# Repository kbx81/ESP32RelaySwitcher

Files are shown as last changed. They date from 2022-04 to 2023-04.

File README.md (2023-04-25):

# kbx's 8-channel ESP32-Powered Relay + I/O Board

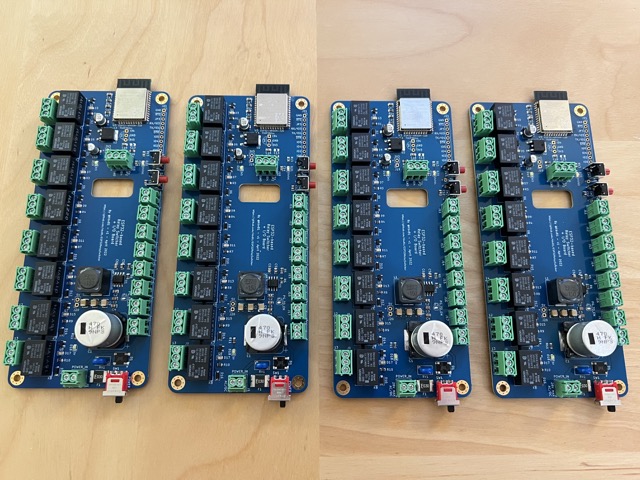
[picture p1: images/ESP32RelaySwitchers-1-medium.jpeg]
kbxESP32RelaySwitcher


## What?

A simple ESP32-based board with eight relays for switching various loads
 as well as terminals for eight external/panel-mounted buttons. Also includes
 a terminal strip for connecting one-wire temperature sensor probes. Designed
 to operate with a 24 VAC power supply.

## Why?

A friend asked me to.

## How?

The schematic and PCB were drawn in [KiCAD](https://www.kicad.org); all project files are contained within this repo.

## Look

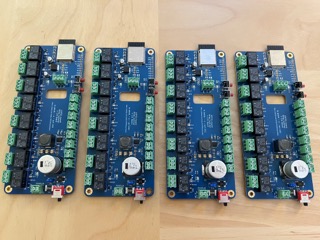
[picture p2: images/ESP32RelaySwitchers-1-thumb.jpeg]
kbxESP32RelaySwitcher

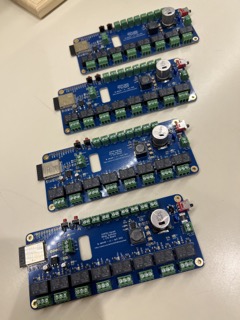
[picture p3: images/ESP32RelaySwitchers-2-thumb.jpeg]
kbxESP32RelaySwitcher

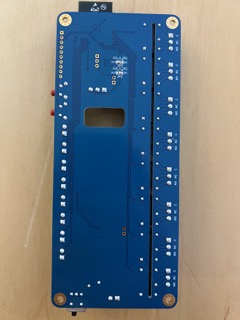
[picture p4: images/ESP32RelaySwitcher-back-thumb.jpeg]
kbxESP32RelaySwitcher


## Legal stuff and License

The circuit schematics and PCB found here are licensed under the
 [Creative Commons Attribution-ShareAlike 4.0 International License](http://creativecommons.org/licenses/by-sa/4.0/).



_Happy building!_

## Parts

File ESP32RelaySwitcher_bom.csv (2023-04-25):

Component | Quantity Per PCB | References | Value | MPN1 | MPN2 | Footprint | Population
1 | 4 | C6 C14 C16 C17 | 100 nF | CC0805KRX7R7BB104 |  | C_0805_2012Metric
2 | 1 | C4 | 220 nF | C2012X5R1H224K125AA |  | C_0805_2012Metric
3 | 2 | C5 C12 | 1 uF | C0805C105K4RACTU |  | C_0805_2012Metric
4 | 2 | C2 C3 | 4.7 uF | C2012X5R1H475K125AB |  | C_0805_2012Metric
5 | 1 | C10 | 10 uF | AFK106M25B12T-F |  | CP_Elec_4x5.8
6 | 1 | C15 | 10 uF | GRM21BC81C106ME15L |  | C_0805_2012Metric
7 | 3 | C7 C8 C9 | 47 uF | GRM32ER61C476KE15L |  | C_1210_3225Metric
8 | 1 | C11 | 100 uF | UWR1A101MCL1GB |  | CP_Elec_5x5.4
9 | 1 | C1 | 470 uF | EEV-FK1H471M |  | CP_Elec_16x17.5
10 | 3 | D18 D19 D20 | 5V | 597-6901-607F |  | LED_0805_2012Metric
11 | 1 | D1 | N/A | CD-MBL206SL |  | Diode_Bridge_Bourns_CD-MBL2xxS
12 | 8 | D2 D4 D6 D8 D10 D12 D14 D16 | N/A | 1N4148W |  | D_SOD-123
13 | 8 | D3 D5 D7 D9 D11 D13 D15 D17 | RELAY_1 | APTL3216CGCK |  | LED_0805_2012Metric
14 | 1 | F1 | 300 mA | 2920L030DR |  | Fuse_2920_7451Metric
15 | 2 | J19 J20 | 3V3 |  |  | PinSocket_1x02_P2.54mm_Vertical
16 | 9 | J1 J11 J12 J13 J14 J15 J16 J17 J18 | POWER_IN | 1984617 |  | TerminalBlock_Phoenix_PT-1,5-2-3.5-H_1x02_P3.50mm_Horizontal
17 | 9 | J2 J3 J4 J5 J6 J7 J8 J9 J10 | RELAY_1 | 1984620 |  | TerminalBlock_Phoenix_PT-1,5-3-3.5-H_1x03_P3.50mm_Horizontal
18 | 1 | J21 | SERIAL+GPIO |  |  | PinSocket_1x10_P2.54mm_Vertical
19 | 8 | K1 K2 K3 K4 K5 K6 K7 K8 | G6E-134P-US DC5 | G6E-134P-US DC5 |  | Relay_SPDT_Omron_G6E
20 | 1 | L1 | 15 uH | 7447709150 | MSS1210-153MEB | L_Wuerth_WE-PD-Typ-LS
21 | 8 | Q1 Q2 Q3 Q4 Q5 Q6 Q7 Q8 | 2N7002 | 2N7002 |  | SOT-23
22 | 1 | R16 | 0 | RC0805FR-070RL |  | R_0805_2012Metric
23 | 8 | R1 R2 R3 R4 R7 R8 R9 R10 | 560 | RT0805FRE07560RL |  | R_0805_2012Metric
24 | 2 | R12 R13 | 1K | RC0805FR-071KL |  | R_0805_2012Metric
25 | 1 | R15 | 4K7 | RC0805FR-074K7L |  | R_0805_2012Metric
26 | 1 | R11 | 8K2 | RT0805FRE078K2L |  | R_0805_2012Metric
27 | 2 | R14 R17 | 10K | RC0805FR-0710KL |  | R_0805_2012Metric
28 | 1 | R6 | 24.9K | RT0805FRE0724K9L |  | R_0805_2012Metric
29 | 1 | R5 | 100K | RC0805FR-07100KL |  | R_0805_2012Metric
30 | 1 | RV1 | N/A | B72205S0400K101 |  | RV_Disc_D7mm_W4mm_P5mm
31 | 1 | SW1 | POWER | 48BFSP1M6QT |  | SW_Push_1P2T_Vertical_E-Switch_800UDP8P1A1M6
32 | 2 | SW2 SW3 | RESET | PTS645VK582LFS |  | SW_Tactile_SPST_Angled_PTS645Vx58-2LFS
33 | 1 | U3 | ESP32-WROOM-32D | ESP32-WROOM-32D |  | ESP32-WROOM-32
34 | 1 | U1 | LMR36520ADDAR | LMR36520ADDAR |  | Texas_HSOP-8-1EP_3.9x4.9mm_P1.27mm_ThermalVias
35 | 1 | U2 | NCP1117-3.3 | LD1117DT33CTR |  | TO-252-2
36 | 1 | U4 | TSOP382xx | TSOP38238 |  | Vishay_MINICAST-3Pin

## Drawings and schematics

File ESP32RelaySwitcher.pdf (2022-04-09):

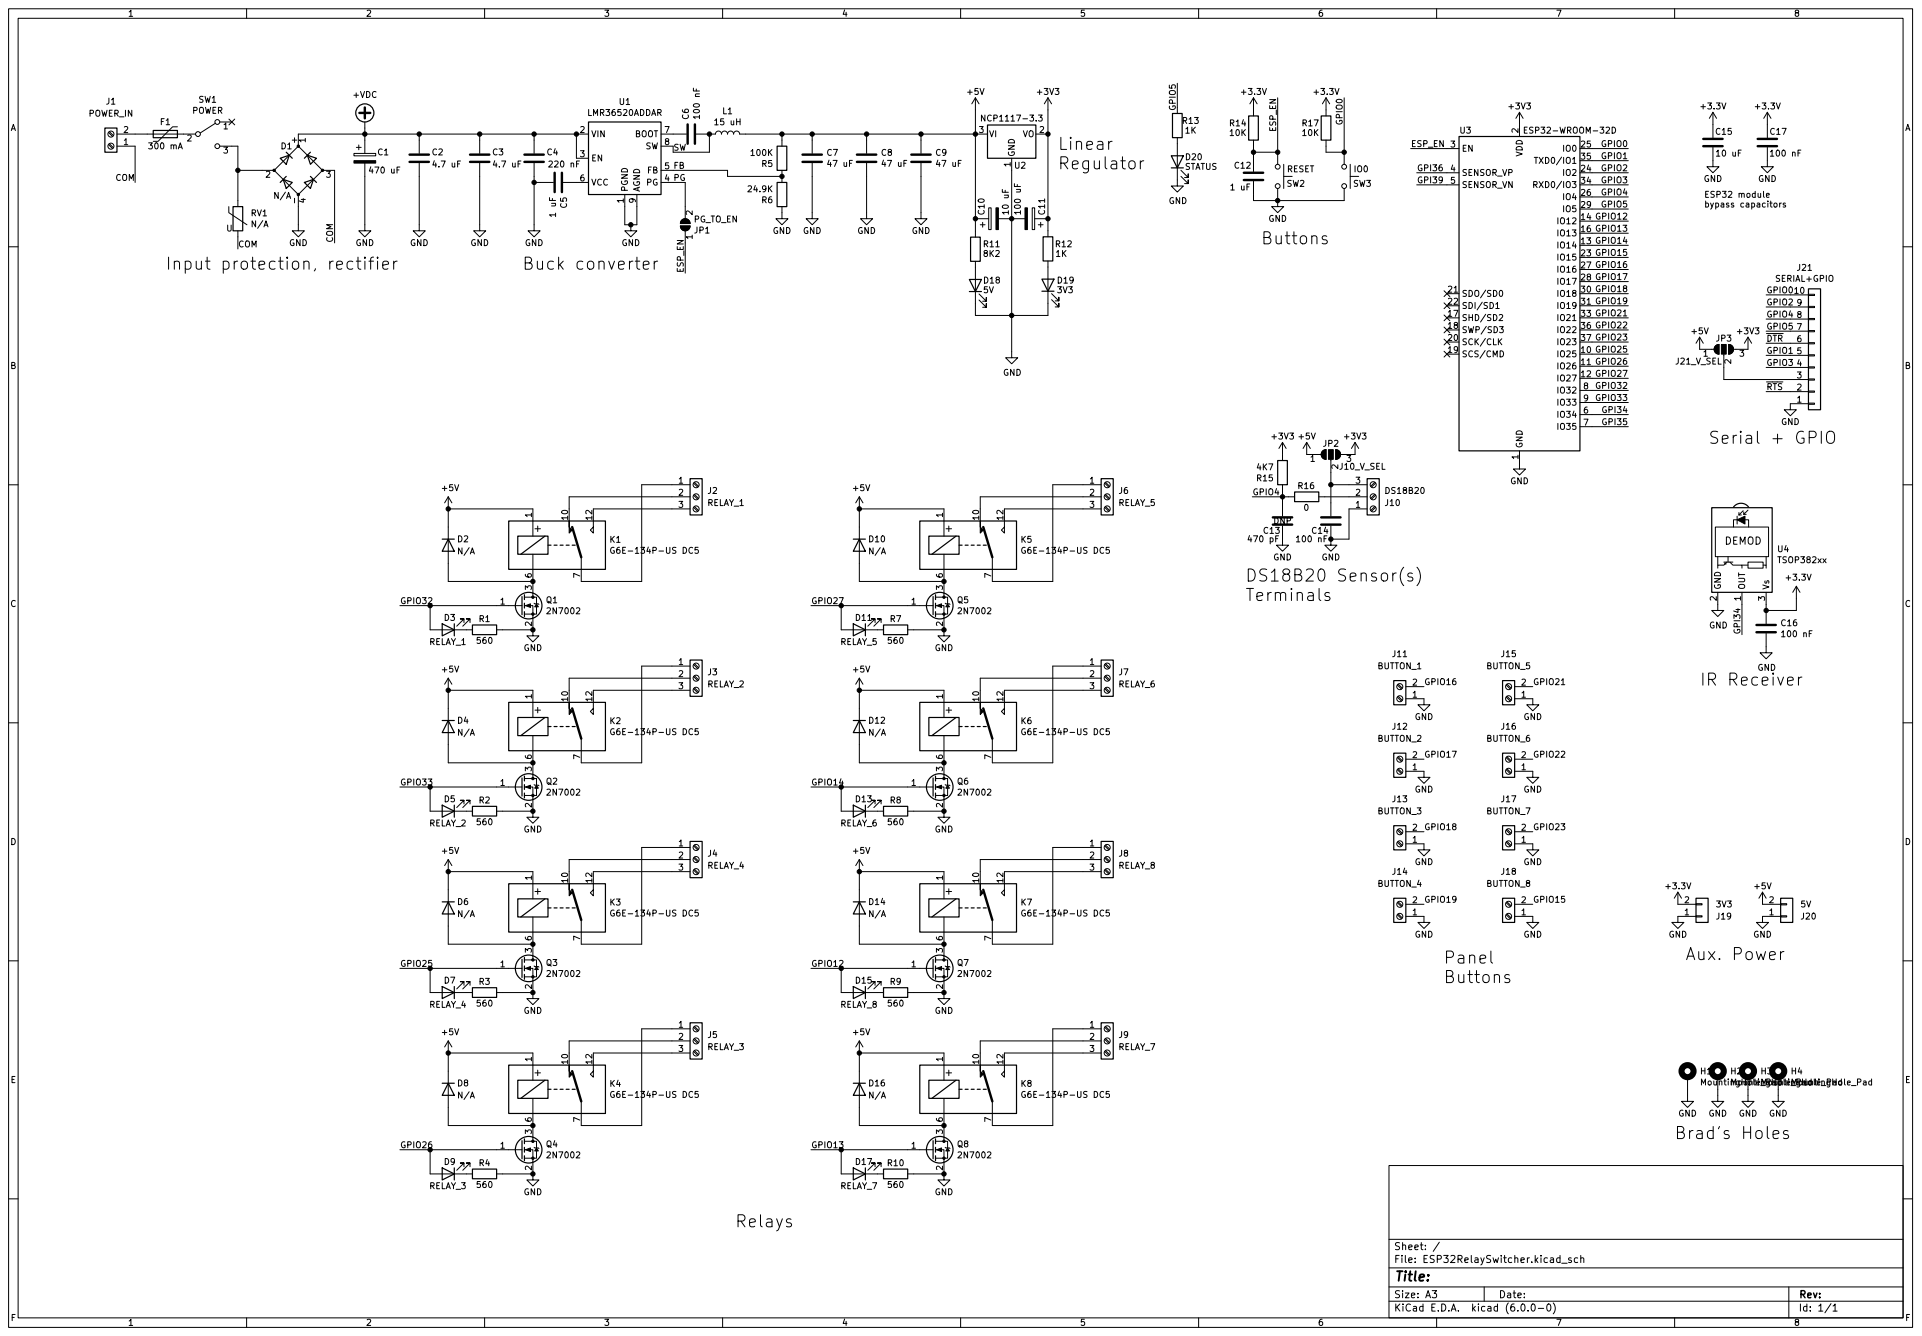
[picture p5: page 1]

1 VIN 2 EN 3 PG 4 FB 5 VCC 6 BOOT 7 SW 8 AGND

2 SCK/CLK 20 SDO/SD0 21 SDI/SD1 22

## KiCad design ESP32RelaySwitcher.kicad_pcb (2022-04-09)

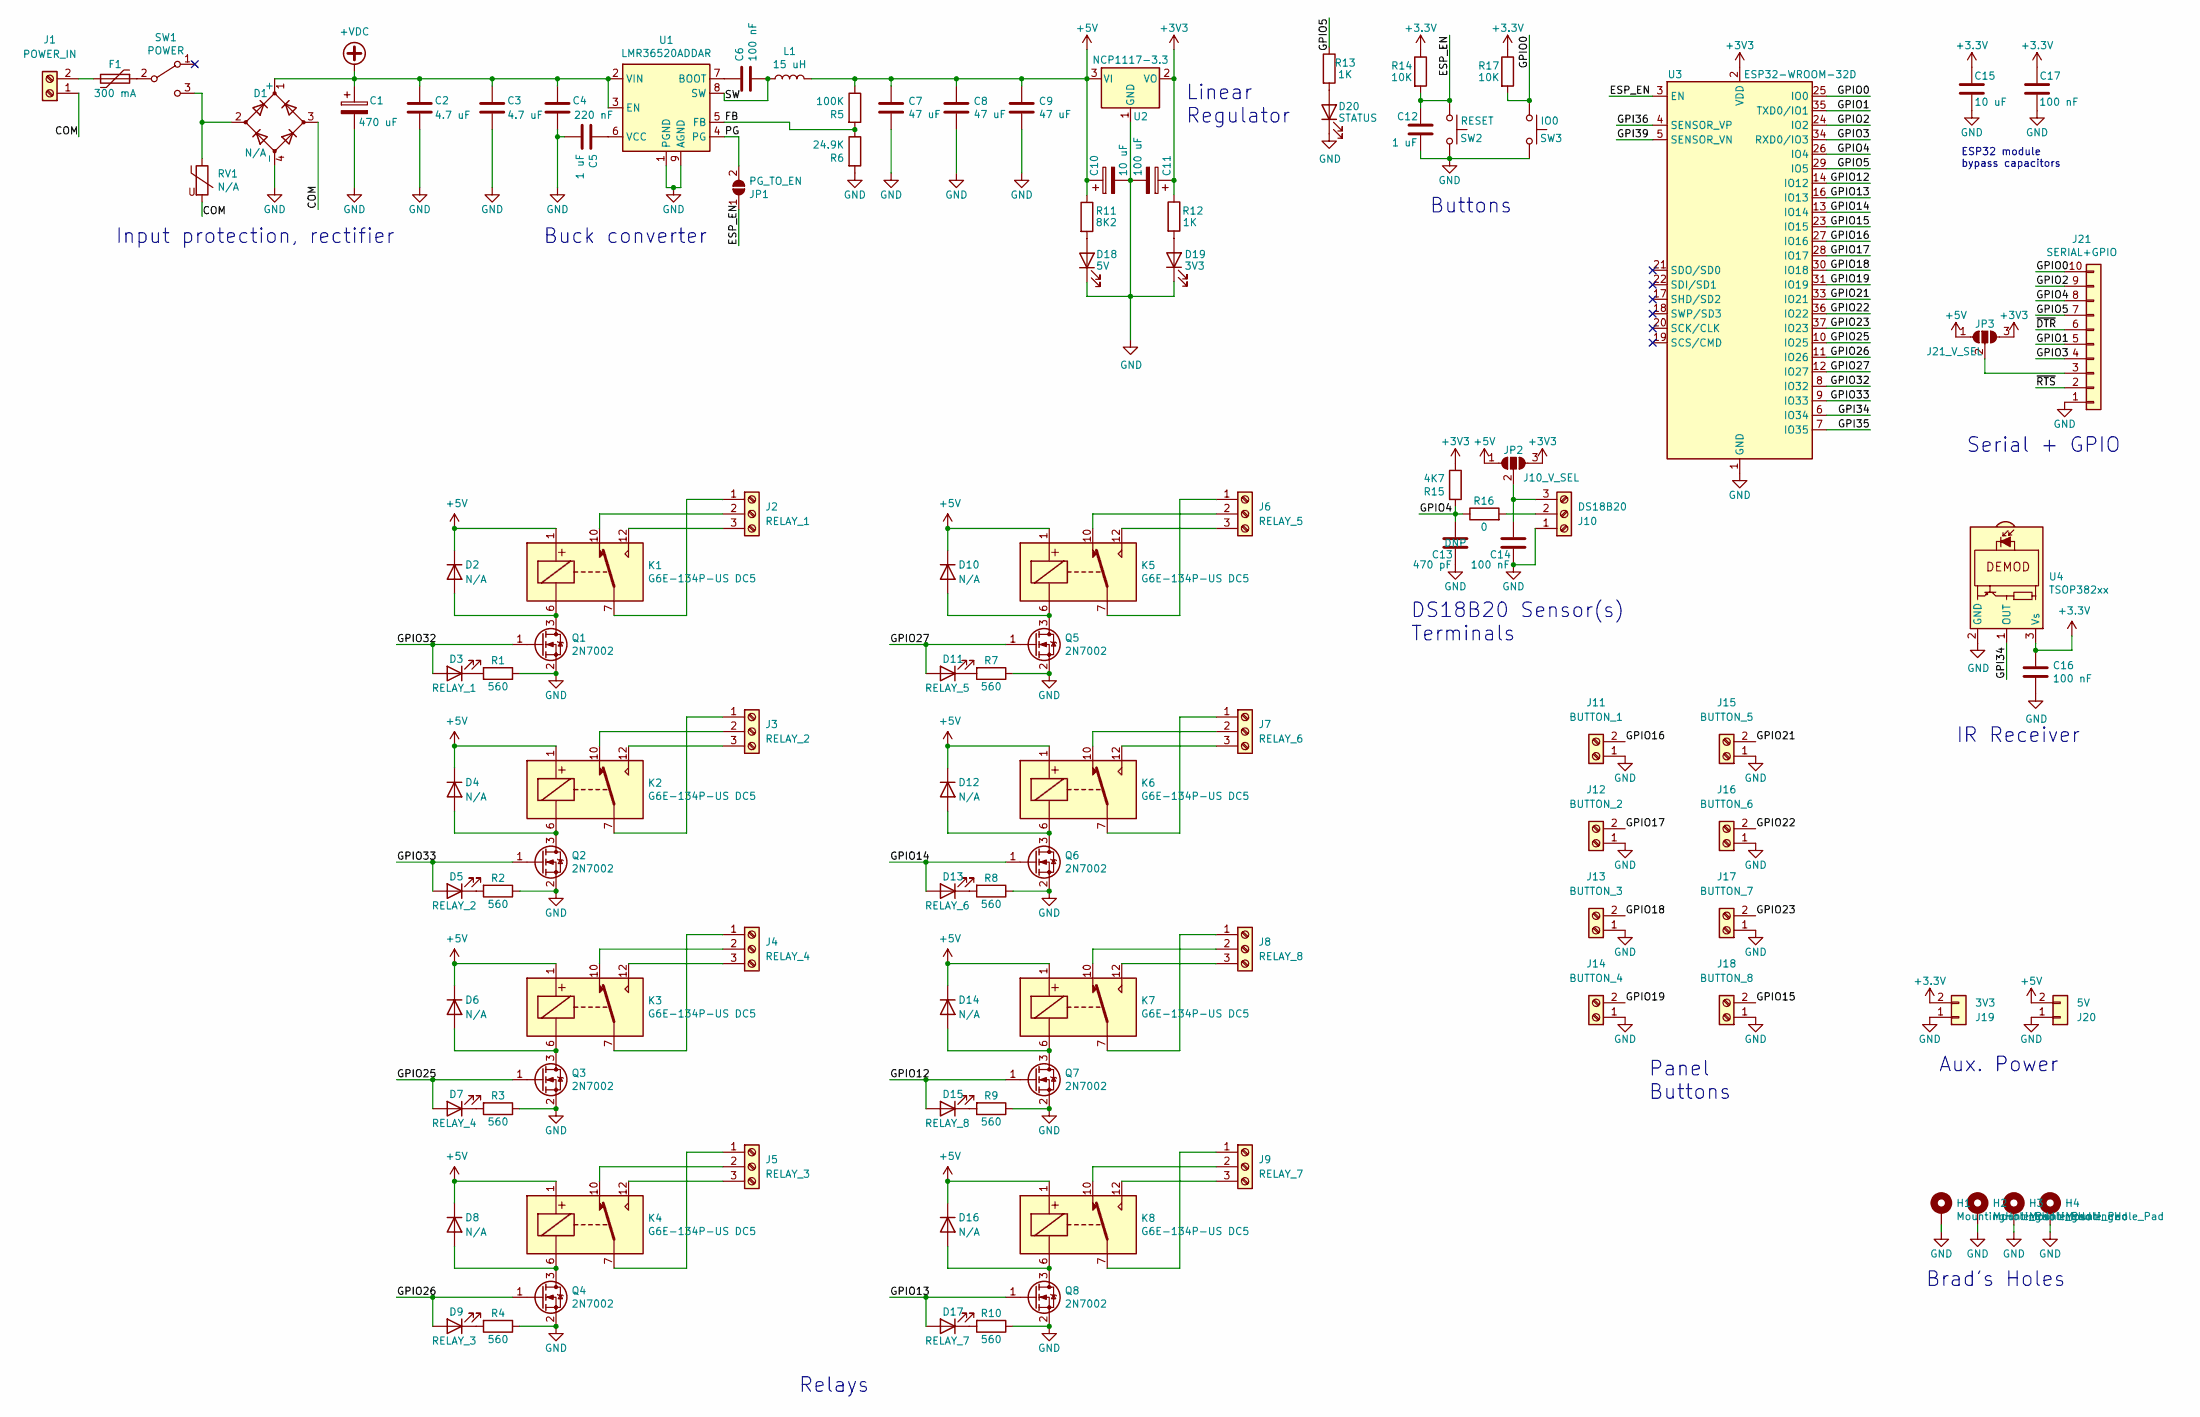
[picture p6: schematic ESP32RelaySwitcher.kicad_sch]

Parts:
C1: 470 uF; CP_Elec_16x17.5; MPN1 EEV-FK1H471M
C2, C3: 4.7 uF; C_0805_2012Metric; MPN1 C2012X5R1H475K125AB
C4: 220 nF; C_0805_2012Metric; MPN1 C2012X5R1H224K125AA
C5: 1 uF; C_0805_2012Metric; MPN1 C0805C105K4RACTU
C6: 100 nF; C_0805_2012Metric; MPN1 CC0805KRX7R7BB104
C7, C8, C9: 47 uF; C_1210_3225Metric; MPN1 GRM32ER61C476KE15L
C10: 10 uF; CP_Elec_4x5.8; Part AFK106M25B12T-F
C11: 100 uF; CP_Elec_5x5.4; Part UWR1A101MCL1GB
C12: 1 uF; C_0805_2012Metric; MPN1 C2012X5R1E105M125AA
C13: 470 pF; C_0805_2012Metric; Part CC0805KRX7R8BB471
C14, C16, C17: 100 nF; C_0805_2012Metric; Part CC0805KRX7R7BB104
C15: 10 uF; C_0805_2012Metric; MPN1 GRM21BC81C106ME15L
D1: N/A; Diode_Bridge_Bourns_CD-MBL2xxS; MPN1 CD-MBL206SL
D2, D4, D6, D8, D10, D12, D14, D16: N/A; D_SOD-123; MPN1 1N4148W
D3: RELAY_1; LED_0805_2012Metric; MPN1 APTL3216CGCK
D5: RELAY_2; LED_0805_2012Metric; MPN1 APTL3216CGCK
D7: RELAY_4; LED_0805_2012Metric; MPN1 APTL3216CGCK
D9: RELAY_3; LED_0805_2012Metric; MPN1 APTL3216CGCK
D11: RELAY_5; LED_0805_2012Metric; MPN1 APTL3216CGCK
D13: RELAY_6; LED_0805_2012Metric; MPN1 APTL3216CGCK
D15: RELAY_8; LED_0805_2012Metric; MPN1 APTL3216CGCK
D17: RELAY_7; LED_0805_2012Metric; MPN1 APTL3216CGCK
D18: 5V; LED_0805_2012Metric; MPN1 597-6901-607F
D19: 3V3; LED_0805_2012Metric; MPN1 597-6901-607F
D20: STATUS; LED_0805_2012Metric; MPN1 597-6901-607F
F1: 300 mA; Fuse_2920_7451Metric; MPN1 2920L030DR
H1, H2, H3, H4: MountingHole_Pad; MountingHole_3.2mm_M3_Pad_Via
J1: POWER_IN; TerminalBlock_Phoenix_PT-1,5-2-3.5-H_1x02_P3.50mm_Horizontal
J2: RELAY_1; TerminalBlock_Phoenix_PT-1,5-3-3.5-H_1x03_P3.50mm_Horizontal
J3: RELAY_2; TerminalBlock_Phoenix_PT-1,5-3-3.5-H_1x03_P3.50mm_Horizontal
J4: RELAY_4; TerminalBlock_Phoenix_PT-1,5-3-3.5-H_1x03_P3.50mm_Horizontal
J5: RELAY_3; TerminalBlock_Phoenix_PT-1,5-3-3.5-H_1x03_P3.50mm_Horizontal
J6: RELAY_5; TerminalBlock_Phoenix_PT-1,5-3-3.5-H_1x03_P3.50mm_Horizontal
J7: RELAY_6; TerminalBlock_Phoenix_PT-1,5-3-3.5-H_1x03_P3.50mm_Horizontal
J8: RELAY_8; TerminalBlock_Phoenix_PT-1,5-3-3.5-H_1x03_P3.50mm_Horizontal
J9: RELAY_7; TerminalBlock_Phoenix_PT-1,5-3-3.5-H_1x03_P3.50mm_Horizontal
J10: DS18B20; TerminalBlock_Phoenix_PT-1,5-3-3.5-H_1x03_P3.50mm_Horizontal
J11: BUTTON_1; TerminalBlock_Phoenix_PT-1,5-2-3.5-H_1x02_P3.50mm_Horizontal
J12: BUTTON_2; TerminalBlock_Phoenix_PT-1,5-2-3.5-H_1x02_P3.50mm_Horizontal
J13: BUTTON_3; TerminalBlock_Phoenix_PT-1,5-2-3.5-H_1x02_P3.50mm_Horizontal
J14: BUTTON_4; TerminalBlock_Phoenix_PT-1,5-2-3.5-H_1x02_P3.50mm_Horizontal
J15: BUTTON_5; TerminalBlock_Phoenix_PT-1,5-2-3.5-H_1x02_P3.50mm_Horizontal
J16: BUTTON_6; TerminalBlock_Phoenix_PT-1,5-2-3.5-H_1x02_P3.50mm_Horizontal
J17: BUTTON_7; TerminalBlock_Phoenix_PT-1,5-2-3.5-H_1x02_P3.50mm_Horizontal
J18: BUTTON_8; TerminalBlock_Phoenix_PT-1,5-2-3.5-H_1x02_P3.50mm_Horizontal
J19: 3V3; PinSocket_1x02_P2.54mm_Vertical
J20: 5V; PinSocket_1x02_P2.54mm_Vertical
J21: SERIAL+GPIO; PinSocket_1x10_P2.54mm_Vertical
JP1: PG_TO_EN; SolderJumper-2_P1.3mm_Open_RoundedPad1.0x1.5mm; MPN1 N/A
JP2: J10_V_SEL; SolderJumper-3_P1.3mm_Open_RoundedPad1.0x1.5mm; MPN1 N/A
JP3: J21_V_SEL; SolderJumper-3_P1.3mm_Open_RoundedPad1.0x1.5mm; MPN1 N/A
K1, K2, K3, K4, K5, K6, K7, K8: G6E-134P-US DC5; Relay_SPDT_Omron_G6E; MPN1 G6E-134P-US DC5
L1: 15 uH; L_Wuerth_WE-PD-Typ-LS; MPN1 7447709150
Q1, Q2, Q3, Q4, Q5, Q6, Q7, Q8: 2N7002; SOT-23; MPN1 2N7002
R1, R2, R3, R4, R7, R8, R9, R10: 560; R_0805_2012Metric; MPN1 RT0805FRE07560RL
R5: 100K; R_0805_2012Metric; MPN1 RC0805FR-07100KL
R6: 24.9K; R_0805_2012Metric; MPN1 RT0805FRE0724K9L
R11: 8K2; R_0805_2012Metric; MPN1 RT0805FRE078K2L
R12, R13: 1K; R_0805_2012Metric; MPN1 RC0805FR-071KL
R14, R17: 10K; R_0805_2012Metric; MPN1 RC0805FR-0710KL
R15: 4K7; R_0805_2012Metric; Part RC0805FR-074K7L
R16: 0; R_0805_2012Metric; Part RC0805FR-070RL
RV1: N/A; RV_Disc_D7mm_W4mm_P5mm; MPN1 B72205S0400K101
SW1: POWER; SW_Push_1P2T_Vertical_E-Switch_800UDP8P1A1M6; MPN1 48BFSP1M6QT
SW2: RESET; SW_Tactile_SPST_Angled_PTS645Vx58-2LFS; MPN1 PTS645VK582LFS
SW3: IO0; SW_Tactile_SPST_Angled_PTS645Vx58-2LFS; MPN1 PTS645VK582LFS
U1: LMR36520ADDAR; Texas_HSOP-8-1EP_3.9x4.9mm_P1.27mm_ThermalVias; MPN1 LMR36520ADDAR
U2: NCP1117-3.3; TO-252-2
U3: ESP32-WROOM-32D; ESP32-WROOM-32; MPN1 ESP32-WROOM-32D
U4: TSOP382xx; Vishay_MINICAST-3Pin

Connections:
+5V: C7.1, C8.1, C9.1, C10.1, D2.1 (K), D4.1 (K), D6.1 (K), D8.1 (K), D10.1 (K), D12.1 (K), D14.1 (K), D16.1 (K), J20.2, JP2.1 (A), JP3.1 (A), K1.1, K2.1, K3.1, K4.1, K5.1, K6.1, K7.1, K8.1, L1.2, R5.1, R11.1, U2.3 (VI)
+VDC: C1.1, C2.1, C3.1, C4.1, D1.1 (+), U1.2 (VIN), U1.3 (EN)
/COM: D1.3, J1.1, RV1.2
/ESP_EN: C12.1, JP1.1 (A), R14.2, SW2.1, U3.3 (EN)
/FB: R5.2, R6.1, U1.5 (FB)
/GPI34: U3.6 (IO34), U4.1 (OUT)
/GPI35: U3.7 (IO35)
/GPI36: U3.4 (SENSOR_VP)
/GPI39: U3.5 (SENSOR_VN)
/GPIO0: J21.10, R17.2, SW3.1, U3.25 (IO0)
/GPIO1: J21.5, U3.35 (TXD0/IO1)
/GPIO2: J21.9, U3.24 (IO2)
/GPIO3: J21.4, U3.34 (RXD0/IO3)
/GPIO4: C13.1, J21.8, R15.2, R16.1, U3.26 (IO4)
/GPIO5: J21.7, R13.1, U3.29 (IO5)
/GPIO12: D15.2 (A), Q7.1 (G), U3.14 (IO12)
/GPIO13: D17.2 (A), Q8.1 (G), U3.16 (IO13)
/GPIO14: D13.2 (A), Q6.1 (G), U3.13 (IO14)
/GPIO15: J18.2, U3.23 (IO15)
/GPIO16: J11.2, U3.27 (IO16)
/GPIO17: J12.2, U3.28 (IO17)
/GPIO18: J13.2, U3.30 (IO18)
/GPIO19: J14.2, U3.31 (IO19)
/GPIO21: J15.2, U3.33 (IO21)
/GPIO22: J16.2, U3.36 (IO22)
/GPIO23: J17.2, U3.37 (IO23)
/GPIO25: D7.2 (A), Q3.1 (G), U3.10 (IO25)
/GPIO26: D9.2 (A), Q4.1 (G), U3.11 (IO26)
/GPIO27: D11.2 (A), Q5.1 (G), U3.12 (IO27)
/GPIO32: D3.2 (A), Q1.1 (G), U3.8 (IO32)
/GPIO33: D5.2 (A), Q2.1 (G), U3.9 (IO33)
/PG: JP1.2 (B), U1.4 (PG)
/SW: C6.2, L1.1, U1.8 (SW)
/~DTR: J21.6
/~RTS: J21.2
GND: C1.2, C2.2, C3.2, C4.2, C5.2, C7.2, C8.2, C9.2, C10.2, C11.2, C12.2, C13.2, C14.2, C15.2, C16.2, C17.2, D1.4 (-), D18.1 (K), D19.1 (K), D20.1 (K), H1.1, H2.1, H3.1, H4.1, J10.1, J11.1, J12.1, J13.1, J14.1, J15.1, J16.1, J17.1, J18.1, J19.1, J20.1, J21.1, Q1.2 (S), Q2.2 (S), Q3.2 (S), Q4.2 (S), Q5.2 (S), Q6.2 (S), Q7.2 (S), Q8.2 (S), R1.1, R2.1, R3.1, R4.1, R6.2, R7.1, R8.1, R9.1, R10.1, SW2.2, SW3.2, U1.1 (PGND), U1.9 (AGND), U2.1 (GND), U3.1 (GND), U3.15 (GND), U3.38 (GND), U3.39 (GND), U4.2 (GND)
unnamed: C5.1, U1.6 (VCC)
unnamed: C6.1, U1.7 (BOOT)
unnamed: C14.1, J10.3, JP2.2 (C)
unnamed: D1.2, RV1.1, SW1.3 (C)
unnamed: D2.2 (A), K1.6, Q1.3 (D)
unnamed: D3.1 (K), R1.2
unnamed: D4.2 (A), K2.6, Q2.3 (D)
unnamed: D5.1 (K), R2.2
unnamed: D6.2 (A), K3.6, Q3.3 (D)
unnamed: D7.1 (K), R3.2
unnamed: D8.2 (A), K4.6, Q4.3 (D)
unnamed: D9.1 (K), R4.2
unnamed: D10.2 (A), K5.6, Q5.3 (D)
unnamed: D11.1 (K), R7.2
unnamed: D12.2 (A), K6.6, Q6.3 (D)
unnamed: D13.1 (K), R8.2
unnamed: D14.2 (A), K7.6, Q7.3 (D)
unnamed: D15.1 (K), R9.2
unnamed: D16.2 (A), K8.6, Q8.3 (D)
unnamed: D17.1 (K), R10.2
unnamed: D18.2 (A), R11.2
unnamed: D19.2 (A), R12.2
unnamed: D20.2 (A), R13.2
unnamed: F1.1, SW1.2 (B)
unnamed: F1.2, J1.2
unnamed: J2.1, K1.7
unnamed: J2.2, K1.10
unnamed: J2.3, K1.12
unnamed: J3.1, K2.7
unnamed: J3.2, K2.10
unnamed: J3.3, K2.12
unnamed: J4.1, K3.7
unnamed: J4.2, K3.10
unnamed: J4.3, K3.12
unnamed: J5.1, K4.7
unnamed: J5.2, K4.10
unnamed: J5.3, K4.12
unnamed: J6.1, K5.7
unnamed: J6.2, K5.10
unnamed: J6.3, K5.12
unnamed: J7.1, K6.7
unnamed: J7.2, K6.10
unnamed: J7.3, K6.12
unnamed: J8.1, K7.7
unnamed: J8.2, K7.10
unnamed: J8.3, K7.12
unnamed: J9.1, K8.7
unnamed: J9.2, K8.10
unnamed: J9.3, K8.12
unnamed: J10.2, R16.2
unnamed: J21.3, JP3.2 (C)

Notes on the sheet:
Buttons
Buck converter
Aux. Power
DS18B20 Sensor(s) Terminals
ESP32 module bypass capacitors
Linear Regulator
Input protection, rectifier
Panel Buttons
Relays
IR Receiver
Brad's Holes
Serial + GPIO

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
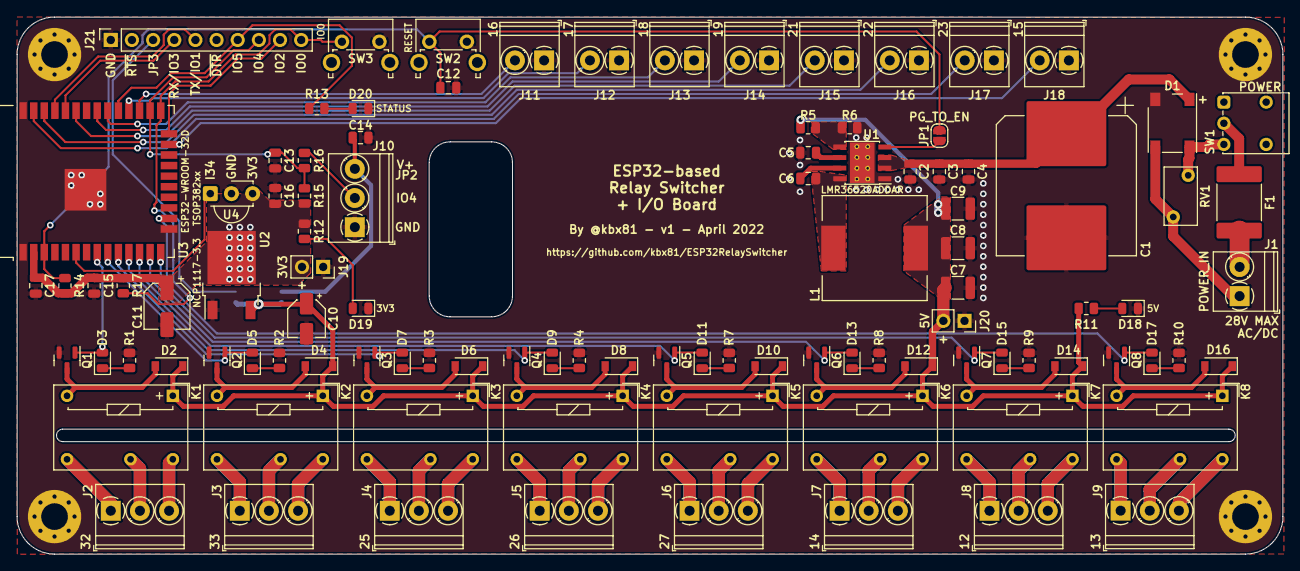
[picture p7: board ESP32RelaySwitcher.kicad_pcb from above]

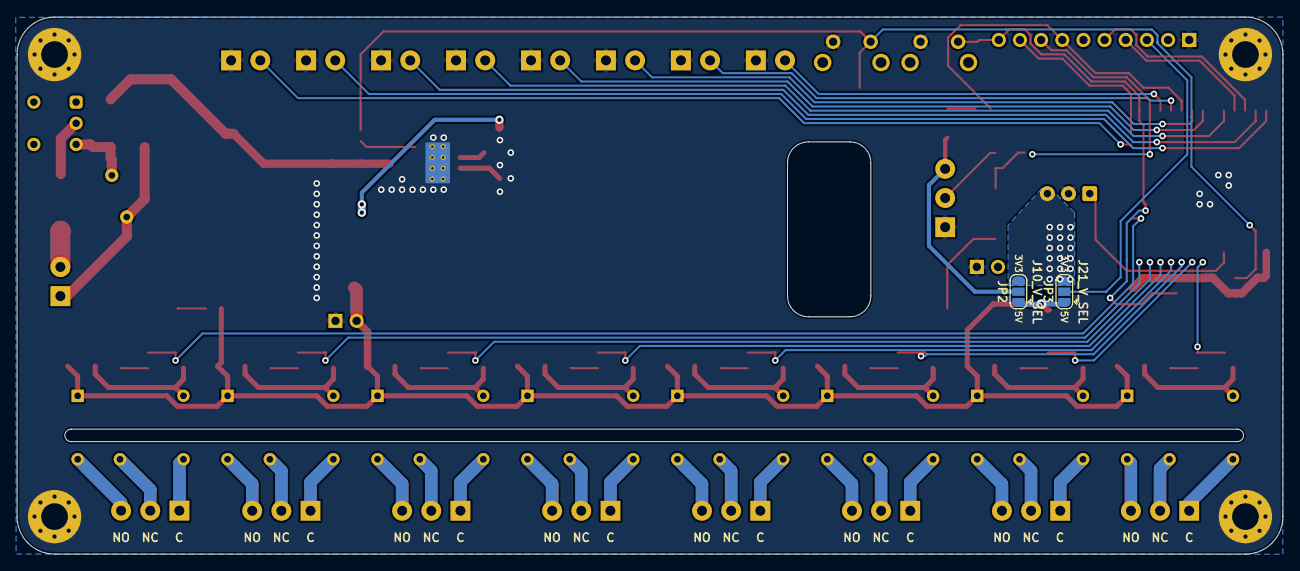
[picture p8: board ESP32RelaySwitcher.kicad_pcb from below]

Board: 2 copper layers, 152.0 x 64.5 mm, 108 parts (2 on the bottom side), 83 nets.

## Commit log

2022-04-09 Use parts I can actually get...
    [ESP32RelaySwitcher-B_Cu.gbr, ESP32RelaySwitcher-B_Mask.gbr, ESP32RelaySwitcher-B_Paste.gbr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]
2022-04-09 Add docs and board render image
2023-04-25 Add BoM, update images
    [ESP32RelaySwitcher.kicad_sch, ESP32RelaySwitcher_bom.csv]
